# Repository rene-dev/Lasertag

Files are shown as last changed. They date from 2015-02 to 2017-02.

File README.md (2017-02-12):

# Lasertag
pew pew!
Ein freies und offenes Lasertag Projekt der warpzone in Münster.

## Aktueller Stand
Hard- und Software haben viele Kinderkrankheiten, spielbar ist es noch nicht. Es existieren 2 Waffel-Prototypen mit tiefgezogenen Gehäusen und ein Paar Hitpoints. Westen wollen noch gebaut werden.
* __Hitpoint__: voll funktionsfähig aber dirty gecoded
* __Lasermodul__: Im groben funktioniert alles. Einige Pins sind falsch beschriftet. IR funktioniert, sendet auch ganz leicht wenn es nicht senden soll. Sound ist viel zu leise.
* __Pi__: Da ist noch einiges zu tun. Grundlegende Kommunikation mit den Modulen ist möglich. Grundlegender Server Client per TCP.

## Grundstruktur
In jeder Waffel steckt ein Raspberry Pi, ein Lasermodul und ein Hitpoint. Das Lasermodul ist ein HAT für den Pi und dient als Schnittstelle zur Waffel-Hardware. Die High-Level Kommunikation (Spielmodus, Powerups, Map, ...) zwischen den Pis läuft per WLAN. Die Low-Level Kommunikation (Player-ID, Schaden) per gebündeltem IR-LED-UART auf TSOP-Empfänger.

### Raspberry Pi
In Python wird Netzwerk gemacht, per I2C die Module angesprochen und das SPI-Touch-Display angesteuert.

### Lasermodul
Kommt in jede Waffel:
* Atmega 328p
* IR-LED zum Daten senden
* roten Laser, damit man auch was sieht (Klasse 1 mit deutschem Zertifikat)
* starke RGBW ansteuern für Lichteffekte
* Trefferzone über einen Front-TSOP
* Taster auslesen
* LiPo auf 5V Step-Up Wandler
* An-Aus Taster
* Akkuüberwachung
* Audioverstärker

### Hitpoint
Kommt in jede Waffel und mehrere an die Weste (Schultern, Bauch, Rücken, ...):
* Attiny 2313A
* 4 10mm RGB-LEDs
* 4 TSOP-IR-Empfänger

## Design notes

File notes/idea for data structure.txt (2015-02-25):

Config:

Waffe
 ID: uint16_t
 Name: string
 Schussmodi[]
  ID: uint16_t
  Munitionsname: string
  Schaden_Schild: uint16_t, Schild/Treffer
  Schaden_Körper: uint16_t, leben/Treffer
  Leben_absaugen: uint16_t, leben/s
  heilen: uint16_t, leben/s
  Schussfrequenz: uint16_t, ms
  Magazingröße: uint32_t
  Anzahl_Schüsse: uint32_t
  Nachladezeit: uint16_t, ms
  Laser_Farbe: uint8_t
  Laser_Schusslänge: uint16_t, ms
  Sound_Schuss: string
  Sound_Schuss_magazin_leer: string
  Sound_nachladen: string
  Sound_getroffen_werden: string
  Haptik
  
Player
 ID: uint16_t
 Name: string
 Team: uint8_t
 Leben: uint16_t
 Leben_max: uint16_t
 Schild: uint16_td
 Schild_max: uint16_t
 aktuelle Waffe: uint16_t
 verfügbare Waffen[]

Spielmodus
 Name: string
 erlaubte Waffen[]
 Teams_janein: boolean
 Team_Anzahl: uint8_t
 Team_maxSpieler: uint8_t
 Scharfschalten mit Knopf vorne: boolean
 Flashlight an bei scharf: teamfarbe, weiss, aus
 TrefferzonenLED_Schultern: teamfarbe, weiss, aus
 TrefferzonenLED_vorne: teamfarbe, weiss, aus
 TrefferzonenLED_hinten: teamfarbe, weiss, aus
 TrefferzonenLED_Waffe: teamfarbe, weiss, aus

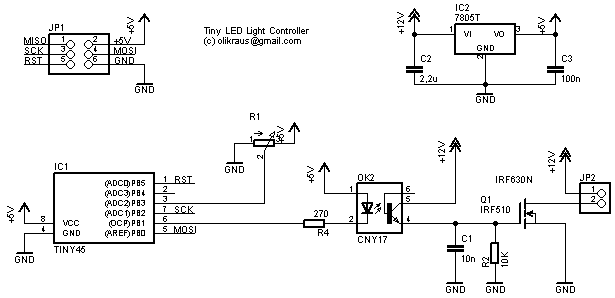
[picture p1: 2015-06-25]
notes/onoff.png

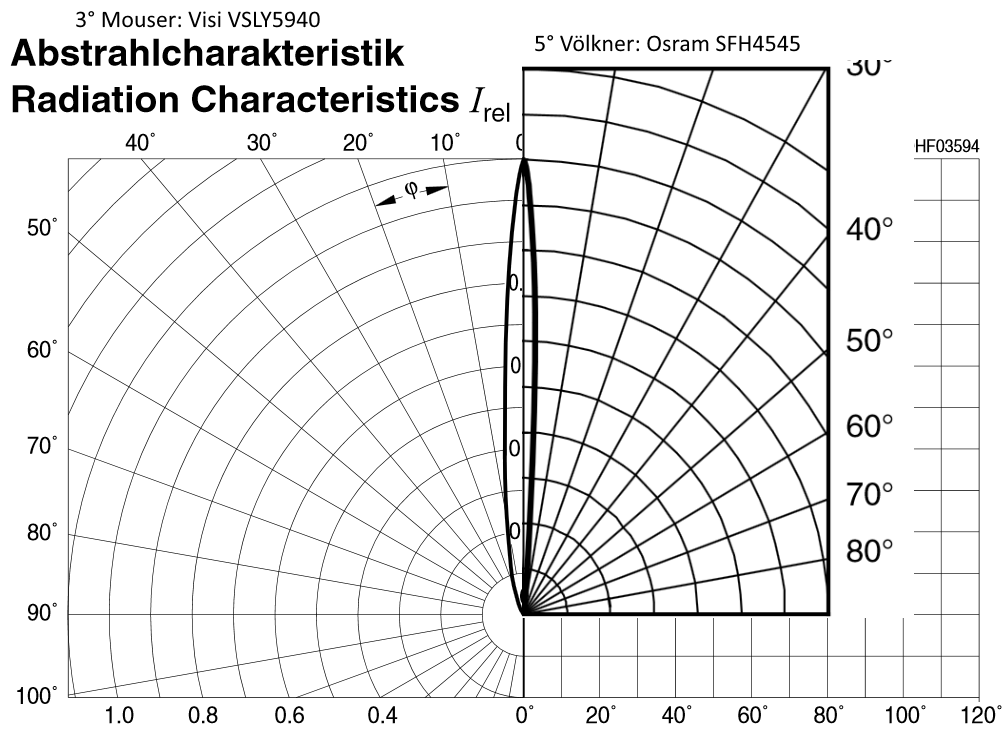
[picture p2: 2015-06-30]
notes/ir led comparison.png

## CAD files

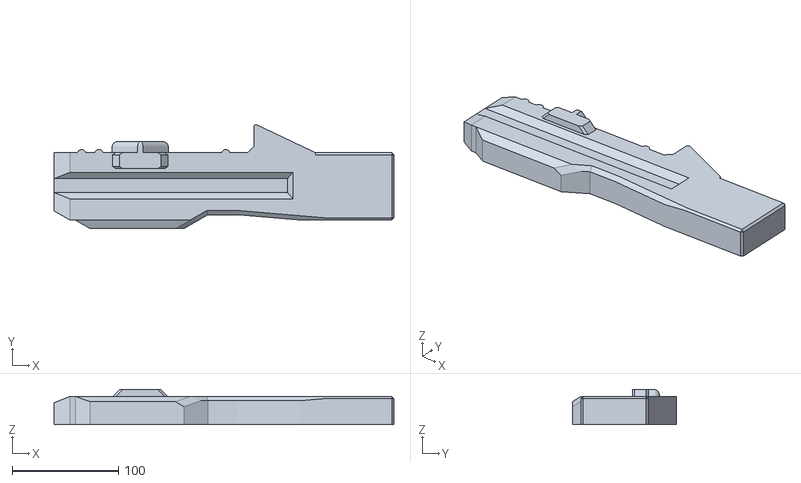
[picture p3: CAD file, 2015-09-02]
case/fräsen/case1a.stl
320.3 x 98.1 x 33.0

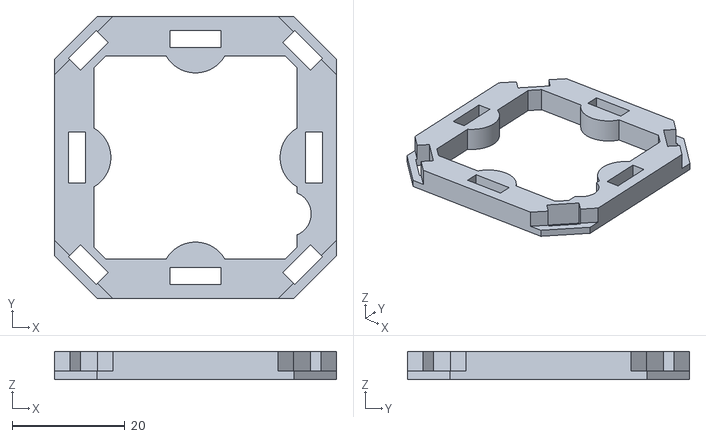
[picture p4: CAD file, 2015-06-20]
hitpoint/3dprinting/hitpoint_frame.stl
50.0 x 50.0 x 5.00

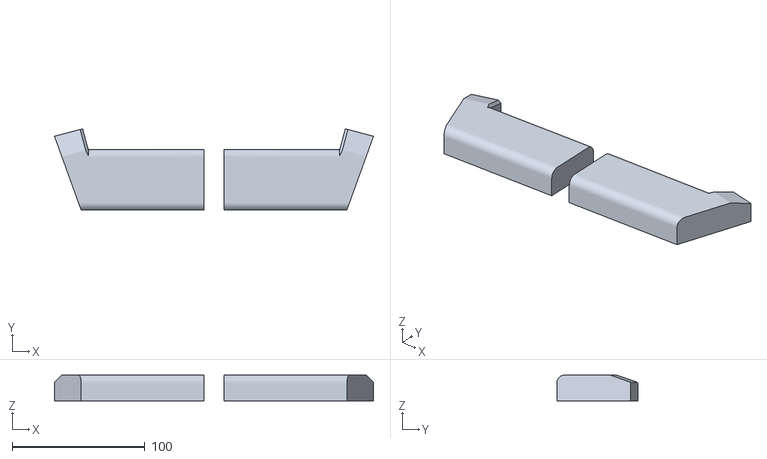
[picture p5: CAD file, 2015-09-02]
case/fräsen/case2.stl
240.7 x 61.5 x 19.5

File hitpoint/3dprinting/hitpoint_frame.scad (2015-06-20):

rotate(90, [1, 0, 0])
{
difference()
{
	// the whole platform
	intersection()
	{
		cube([50, 5, 50], center = true);
		rotate(45, [0, 1, 0])
			cube([60, 5, 60], center = true);
	}
	for(i=[0:3])
	{
		rotate(i*90, [0, 1, 0])
		{
			// ir recv pin holes
			translate([19, 0, 19])
				rotate(45, [0, 1, 0])
					cube([7, 5, 3], center = true);

			translate([23, 0.75, 23])
				intersection()
				{
					rotate(45, [0, 1, 0])
						cube([20, 3.5, 9], center = true);
				}

			// led pin holes
			translate([0, 0, 21])
				cube([9, 5, 3], center = true);
		}
	}

	difference()
	{
		// big hole in the center
		intersection()
		{
			cube([36, 5, 36], center = true);
			rotate(45, [0, 1, 0])
				cube([48, 5, 48], center = true);
		}
		// led platforms
		for(i=[0:3])
		{
			rotate(i*90, [0, 1, 0])
			{
				translate([0, 0, 21])
					rotate(90, [1, 0, 0])
						cylinder(r = 12/2, h = 5, center = true, $fn = 360);
			}
		}
	}

	// capacitor
	translate([16.5, 0, 10])
		rotate(90, [1, 0, 0])
			cylinder(r = 8/2, h = 6, center = true, $fn = 360);
}
}

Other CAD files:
case/fräsen/case1b.stl
case/IR sende dings.skp
case/Lautsprecher.skp
case/case.skp
case/zutaten/Raspberry-Pi-B+-slp.skp

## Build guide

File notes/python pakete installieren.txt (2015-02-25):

sudo apt-get install python-pip
sudo apt-get install python-twisted

pip updaten:
sudo pip install -U pip
sudo pip install --upgrade setuptools

sudo pip install twisted

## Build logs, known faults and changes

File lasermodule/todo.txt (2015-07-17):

ripup @;
layer cream und mask
min leiterbahnbreite 0,032 inch =0,8mm für 4a
pgnd, agnd? am amp? masseführung?
analog spule, 100n?
benennung
pi connector spiegelung
atmega vor den step up? nö
battery connector mehr als 1a
kann backlight pwm pi pin auch pwm?
4,7u nach ldo reichen??
lötjumper r kombipad zum durchschneiden am amp
spule
lötjumper an p-fet pi
extension port evtl jst-xh?
alle gnd pinne vom pi nehmen

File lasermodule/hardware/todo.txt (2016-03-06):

schrift weiter weg von kleinfutter
atmega schrift drehen
3,3, 5v? an ldoschreiben
opto diode markieren
onoff an 2 atmegapins !? pb0 ist gut
ok=ltv817
r25=3,3k
tasterfootprints für anaus
display connector beschriftung
elkos beide seiten + und beschriftung
lcd backlight an +!! und nicht an den uln
wirklich 2 laser nötig?
laser und so anschluss nach vorne?
wo ist haptik?
 am besten: laser_2 = laser_1, laser_1 = haptik (weil pwm)
ok richtung anzeichnen
fets an und rev nicht lesbar wenn verlötet
optionale an led: 2kohm an 5v

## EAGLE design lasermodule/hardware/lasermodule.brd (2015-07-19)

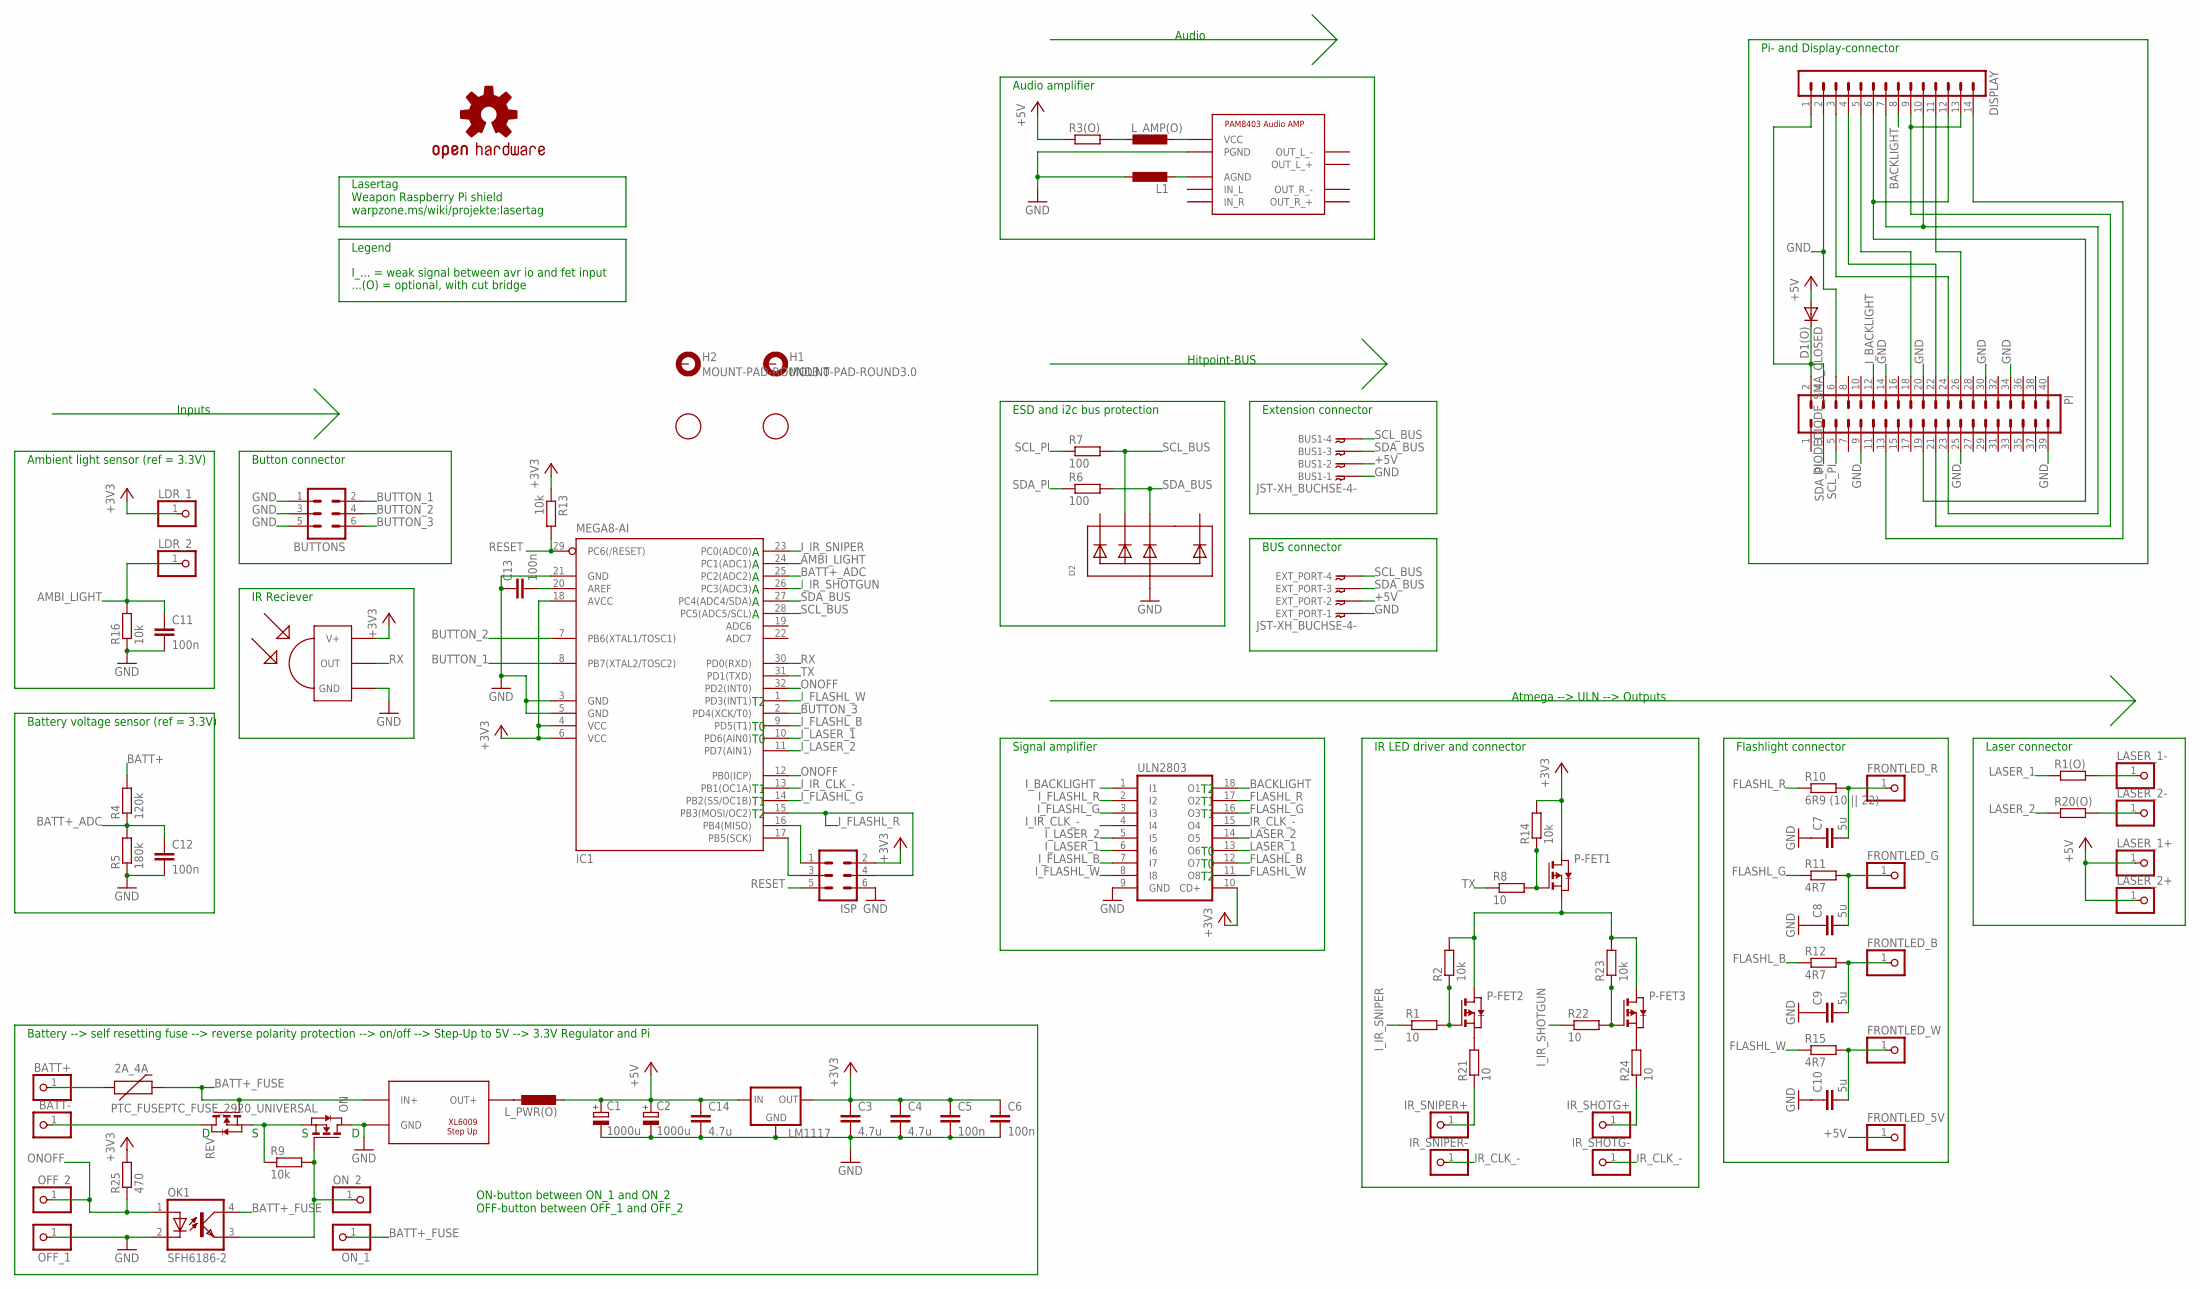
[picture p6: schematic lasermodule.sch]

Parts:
2A_4A: PTC_FUSEPTC_FUSE_2920_UNIVERSAL; PTC_FUSE_2920_UNIVERSAL
BATT+: PIN-HEADER-1PIN-HEADER-1_BIG; PIN-HEADER-1_BIG
BATT-: PIN-HEADER-1PIN-HEADER-1_BIG; PIN-HEADER-1_BIG
BUS1: JST-XH_BUCHSE-4-; JST-XH_BUCHSE-4
BUTTONS: PIN-HEADER-3X2
C1, C2: 1000u; C_UNIVERSAL_PAD
C3, C4, C14: 4.7u; 0805
C5, C6, C11, C12, C13: 100n; 0603
C7, C8, C9, C10: 5u; 0805
D1(O): DIODEDIODE_SMA_CLOSED; DIODE_SMA_CLOSED
D2: ESD-SCHUTZ; SOT363
DISPLAY: PIN-HEADER-DISPLAY
EXT_PORT: JST-XH_BUCHSE-4-; JST-XH_BUCHSE-4
FRONTLED_5V: PIN-HEADER-1PIN-HEADER-1; PIN-HEADER-1
FRONTLED_B: PIN-HEADER-1PIN-HEADER-1; PIN-HEADER-1
FRONTLED_G: PIN-HEADER-1PIN-HEADER-1; PIN-HEADER-1
FRONTLED_R: PIN-HEADER-1PIN-HEADER-1; PIN-HEADER-1
FRONTLED_W: PIN-HEADER-1PIN-HEADER-1; PIN-HEADER-1
H1, H2: MOUNT-PAD-ROUND3.0; 3,0-PAD
IC1: MEGA8-AI; TQFP32-08
IR_SHOTG+: PIN-HEADER-1PIN-HEADER-1; PIN-HEADER-1
IR_SHOTG-: PIN-HEADER-1PIN-HEADER-1; PIN-HEADER-1
IR_SNIPER+: PIN-HEADER-1PIN-HEADER-1; PIN-HEADER-1
IR_SNIPER-: PIN-HEADER-1PIN-HEADER-1; PIN-HEADER-1
ISP: PIN-HEADER-3X2
L1: L-EUL2825P; L2825P
LASER_1+, LASER_1-, LASER_2+, LASER_2-: PIN-HEADER-1PIN-HEADER-1; PIN-HEADER-1
LDR_1, LDR_2: PIN-HEADER-1PIN-HEADER-1; PIN-HEADER-1
LM1117: LM1117_3V3_REGULATOR; SOT223
LOGO1: OSHW-LOGOM; OSHW-LOGO-M
L_AMP(O): L; L_5MM_CLOSED
L_PWR(O): L; L_5MM_CLOSED
OFF_1, OFF_2: PIN-HEADER-1PIN-HEADER-1; PIN-HEADER-1
OK1: SFH6186-2; SMD4-7
ON: N-MOSFET; TO252
ON_1, ON_2: PIN-HEADER-1PIN-HEADER-1; PIN-HEADER-1
P-FET1, P-FET2, P-FET3: PMOSSOT23; SOT-23
PI: PIN-HEADER-20X2
R1, R8, R21, R22, R24: 10; 0603
R1(O), R20(O): R_EU0603_CLOSED; 0603_CLOSED
R2, R9, R13, R14, R16, R23: 10k; 0603
R3(O): R_EU0805_CLOSED; 0805_CLOSED
R4: 120k; 0603
R5: 180k; 0603
R6, R7: 100; 0603
R10: 6R9 (10 || 22); 0603
R11, R12, R15: 4R7; 0603
R25: 470; 0603
REV: N-MOSFET; TO252
U$1: TSOP1838; TSOP18XX
U$3: XL6009-STEPUP-BOARD
U$4: PAM8403-AMP-BOARD
U$5, U$6: FIDUCIAL; FIDUCIAL_1MM
ULN2803: ULN2803ASO18; SO18W

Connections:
+3V3: C3.1, C4.1, C5.1, C6.1, IC1.4 (VCC), IC1.6 (VCC), IC1.18 (AVCC), ISP.2, LDR_1.1, LM1117.2 (OUT), LM1117.4 (OUT), P-FET1.1 (D), R13.1, R14.2, R25.2, U$1.VCC (V+), ULN2803.10 (CD+)
+5V: BUS1.P$2, C1.+, C2.+, C14.1, D1(O).A, EXT_PORT.P$2, FRONTLED_5V.1, LASER_1+.1, LASER_2+.1, LM1117.3 (IN), L_PWR(O).2, R3(O).1
AMBI_LIGHT: C11.1, IC1.24 (PC1(ADC1)), LDR_2.1, R16.2
BACKLIGHT: DISPLAY.8, ULN2803.18 (O1)
BATT+: 2A_4A.P$1 (1), BATT+.1, R4.2
BATT+_ADC: C12.1, IC1.25 (PC2(ADC2)), R4.1, R5.2
BATT+_FUSE: 2A_4A.P$2 (2), OK1.4 (COL), ON_1.1, REV.1 (G), U$3.IN+
BATT-: BATT-.1, REV.3 (D)
BUTTON_1: BUTTONS.2, IC1.8 (PB7(XTAL2/TOSC2))
BUTTON_2: BUTTONS.4, IC1.7 (PB6(XTAL1/TOSC1))
BUTTON_3: BUTTONS.6, IC1.2 (PD4(XCK/T0))
EASTEREGG_NET: P-FET1.2 (S), P-FET2.1 (D), P-FET3.1 (D), R2.2, R23.2
FLASHL_B: R12.1, ULN2803.12 (O7)
FLASHL_G: R11.1, ULN2803.16 (O3)
FLASHL_R: R10.1, ULN2803.17 (O2)
FLASHL_W: R15.1, ULN2803.11 (O8)
GND: BUS1.P$1, BUTTONS.1, BUTTONS.3, BUTTONS.5, C1.-, C2.-, C3.2, C4.2, C5.2, C6.2, C7.1, C8.1, C9.1, C10.1, C11.2, C12.2, C13.1, C14.2, D2.2 (A), DISPLAY.2, EXT_PORT.P$1, IC1.3 (GND), IC1.5 (GND), IC1.21 (GND), ISP.6, L1.1, LM1117.1 (GND), OFF_1.1, OK1.2 (C), ON.3 (D), PI.6, PI.9, PI.14, PI.20, PI.25, PI.30, PI.34, PI.39, R5.1, R16.1, U$1.GND, U$3.GND_IN (GND), U$3.GND_OUT (GND), U$4.PGND, ULN2803.9 (GND)
IR_CLK_-: IR_SHOTG-.1, IR_SNIPER-.1, ULN2803.15 (O4)
IR_SHOTGUN_TX_+: IR_SHOTG+.1, R24.1
IR_SNIPER_TX_+: IR_SNIPER+.1, R21.1
I_BACKLIGHT: PI.12, ULN2803.1 (I1)
I_FLASHL_B: IC1.9 (PD5(T1)), ULN2803.7 (I7)
I_FLASHL_G: IC1.14 (PB2(SS/OC1B)), ULN2803.3 (I3)
I_FLASHL_R: IC1.15 (PB3(MOSI/OC2)), ISP.4, ULN2803.2 (I2)
I_FLASHL_W: IC1.1 (PD3(INT1)), ULN2803.8 (I8)
I_IR_CLK_-: IC1.13 (PB1(OC1A)), ULN2803.4 (I4)
I_IR_SHOTGUN: IC1.26 (PC3(ADC3)), R22.1
I_IR_SNIPER: IC1.23 (PC0(ADC0)), R1.1
I_LASER_1: IC1.10 (PD6(AIN0)), ULN2803.6 (I6)
I_LASER_2: IC1.11 (PD7(AIN1)), ULN2803.5 (I5)
LASER_1: R1(O).1, ULN2803.13 (O6)
LASER_1-: LASER_1-.1, R1(O).2
LASER_2: R20(O).1, ULN2803.14 (O5)
LASER_2-: LASER_2-.1, R20(O).2
LCD_CS: DISPLAY.3, PI.24
LCD_DC: DISPLAY.5, PI.18
LCD_MISO: DISPLAY.9, DISPLAY.13, PI.21
LCD_MOSI: DISPLAY.6, DISPLAY.12, PI.19
LCD_RESET: DISPLAY.4, PI.22
LCD_SCK: DISPLAY.7, DISPLAY.10, PI.23
LCD_TOUCH_CS: DISPLAY.11, PI.26
LCD_TOUCH_IRQ: DISPLAY.14, PI.13
unnamed: L1.2, U$4.AGND
unnamed: IC1.16 (PB4(MISO)), ISP.1
unnamed: IC1.17 (PB5(SCK)), ISP.3
unnamed: C7.2, FRONTLED_R.1, R10.2
unnamed: P-FET1.3 (G), R8.2, R14.1
unnamed: C13.2, IC1.20 (AREF)
unnamed: P-FET2.3 (G), R1.2, R2.1
unnamed: C8.2, FRONTLED_G.1, R11.2
unnamed: C9.2, FRONTLED_B.1, R12.2
unnamed: C10.2, FRONTLED_W.1, R15.2
unnamed: L_PWR(O).1, U$3.OUT+
unnamed: ON.2 (S), R9.1, REV.2 (S)
unnamed: P-FET2.2 (S), R21.2
unnamed: D1(O).C, DISPLAY.1, PI.2, PI.4
unnamed: L_AMP(O).2, R3(O).2
unnamed: L_AMP(O).1, U$4.VCC
unnamed: P-FET3.2 (S), R24.2
unnamed: P-FET3.3 (G), R22.2, R23.1
ONOFF: IC1.12 (PB0(ICP)), IC1.32 (PD2(INT0)), OFF_2.1, OK1.1 (A), R25.1
ONOFF_2: OK1.3 (EMIT), ON.1 (G), ON_2.1, R9.2
RESET: IC1.29 (PC6(/RESET)), ISP.5, R13.2
RX: IC1.30 (PD0(RXD)), U$1.OUT
SCL_BUS: BUS1.P$4, D2.3 (C2), EXT_PORT.P$4, IC1.28 (PC5(ADC5/SCL)), R7.2
SCL_PI: PI.5, R7.1
SDA_BUS: BUS1.P$3, D2.4 (C3), EXT_PORT.P$3, IC1.27 (PC4(ADC4/SDA)), R6.2
SDA_PI: PI.3, R6.1
TX: IC1.31 (PD1(TXD)), R8.1

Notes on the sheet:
Flashlight connector
Laser connector
BUS connector
ESD and i2c bus protection
IR Reciever
Audio amplifier
Battery --> self resetting fuse --> reverse polarity protection --> on/off --> Step-Up to 5V --> 3.3V Regulator and Pi
Pi- and Display-connector
Battery voltage sensor (ref = 3.3V)
Ambient light sensor (ref = 3.3V)
IR LED driver and connector
Signal amplifier
Button connector
Extension connector
I_... = weak signal between avr io and fet input
Legend
...(O) = optional, with cut bridge
Hitpoint-BUS
ON-button between ON_1 and ON_2 OFF-button between OFF_1 and OFF_2
Atmega --> ULN --> Outputs
Inputs
Audio
Lasertag Weapon Raspberry Pi shield warpzone.ms/wiki/projekte:lasertag

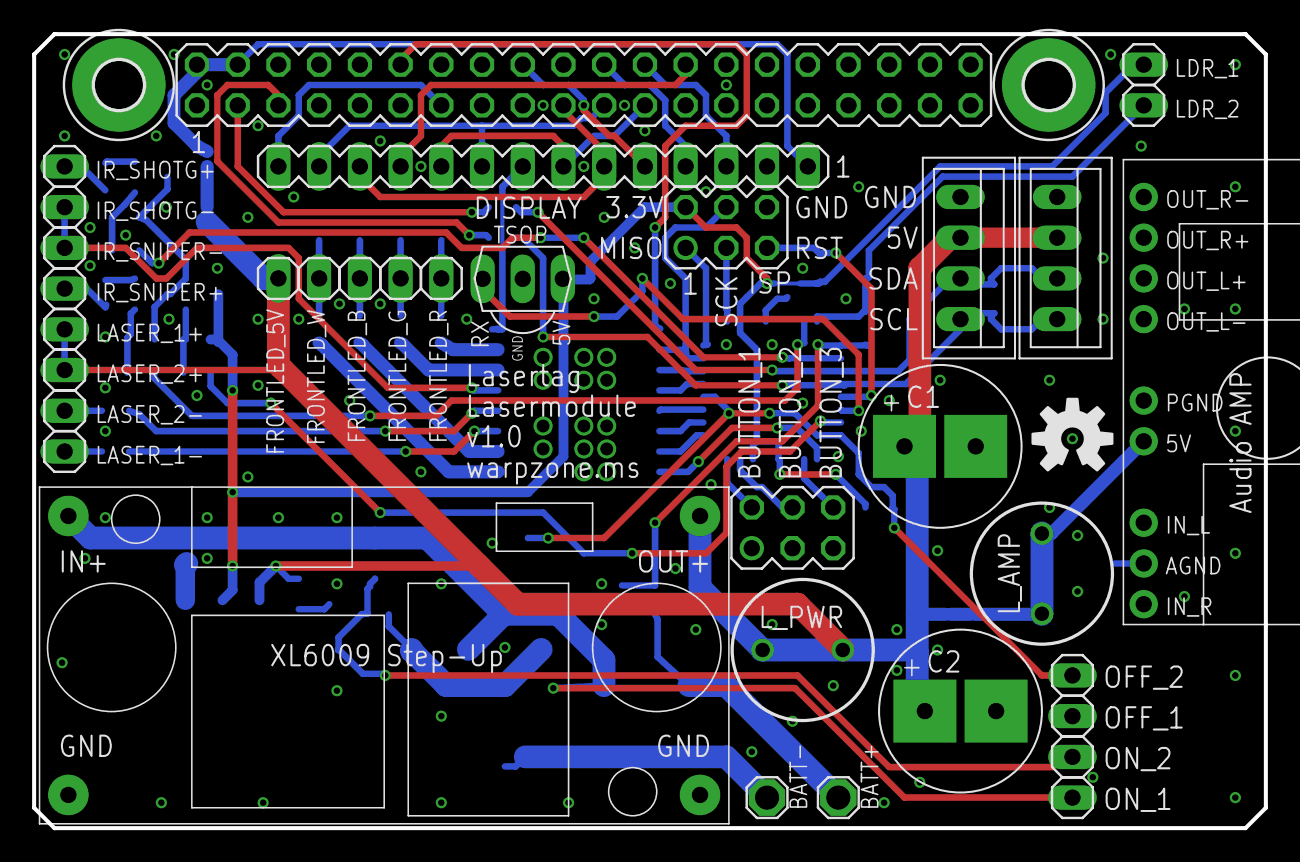
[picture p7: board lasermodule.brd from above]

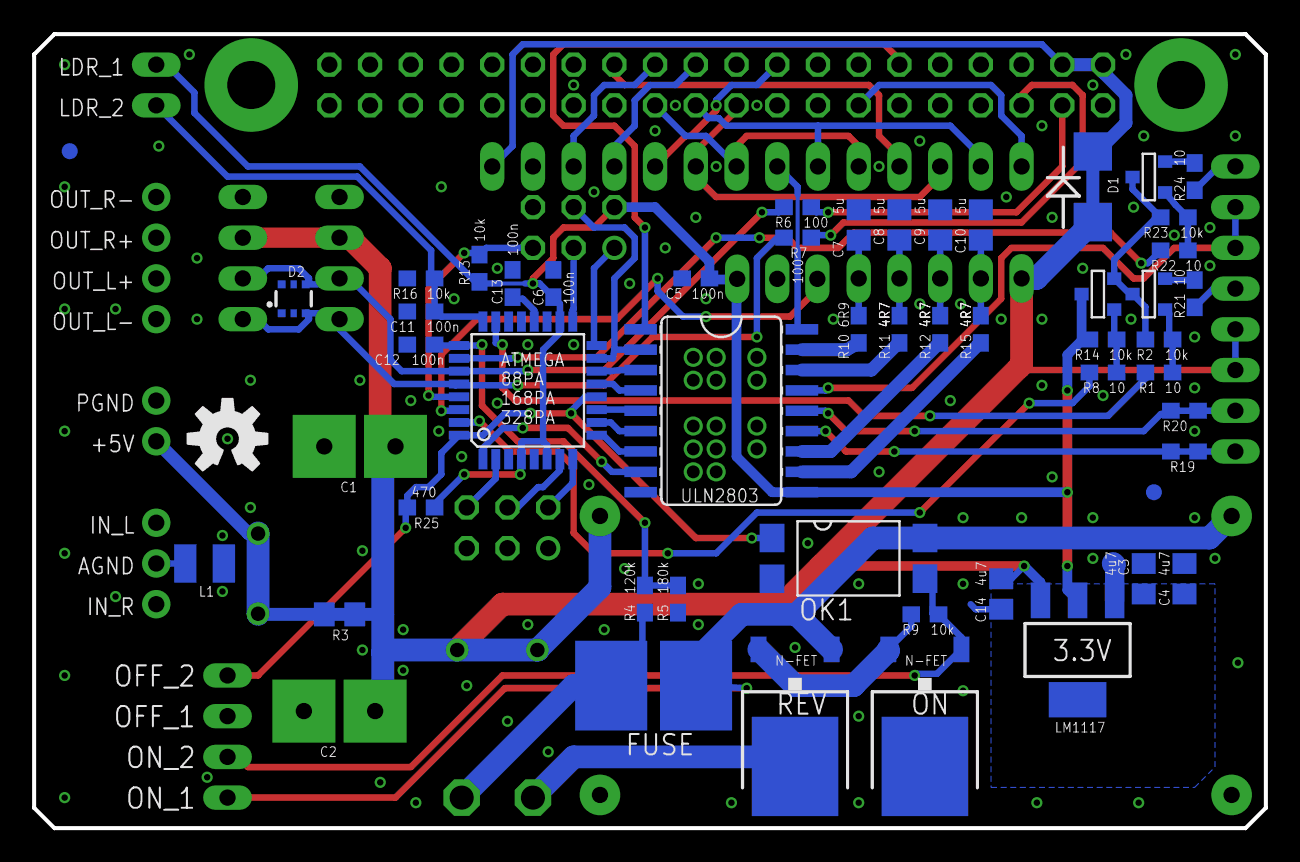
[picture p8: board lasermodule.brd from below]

Board: 2 copper layers, 76.8 x 49.5 mm, 89 parts (51 on the bottom side), 69 nets.

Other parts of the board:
LOGO2: OSHW-LOGOM; OSHW-LOGO-M
U$2: PI2

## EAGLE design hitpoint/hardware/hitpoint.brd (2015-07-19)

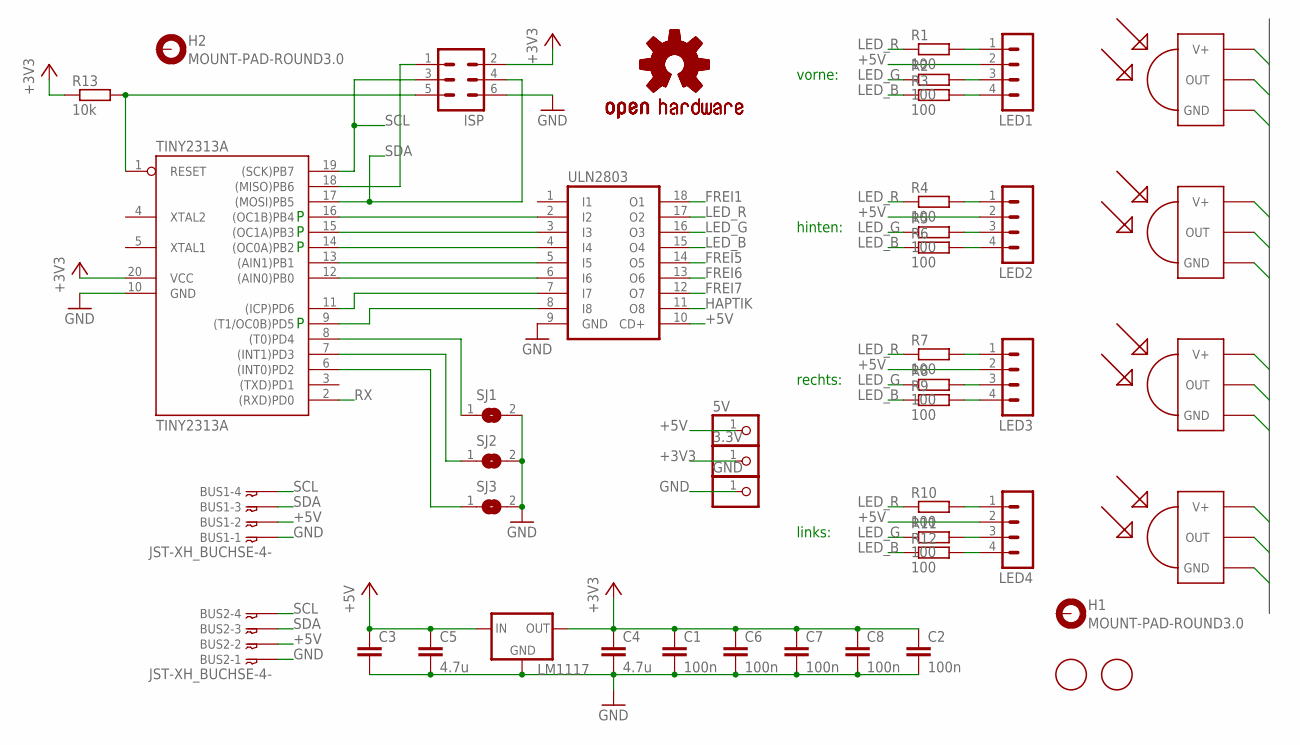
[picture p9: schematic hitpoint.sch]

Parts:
3.3V, 5V: PIN-HEADER-1
BUS1, BUS2: JST-XH_BUCHSE-4-; JST-XH_BUCHSE-4
C1, C2, C6, C7, C8: 100n; 0603
C3: C_EUCAP_UNIVERSAL; C_UNIVERSAL
C4, C5: 4.7u; 0805
GND: PIN-HEADER-1
H1, H2: MOUNT-PAD-ROUND3.0; 3,0-PAD
ISP: PIN-HEADER-3X2
LED1, LED2, LED3, LED4: PIN-HEADER-4
LM1117: LM1117_3V3_REGULATOR; SOT223
LOGO1, LOGO2: OSHW-LOGOM; OSHW-LOGO-M
R1, R2, R3, R4, R5, R6, R7, R8, R9, R10, R11, R12: 100; 0603
R13: 10k; 0603
SJ1, SJ2, SJ3: SJ
TINY2313A: TINY2313A; SO20LVERSTUMMELT
U$1, U$2, U$3, U$4: TSOP4338
U$5, U$6: FIDUCIAL; FIDUCIAL_1MM
ULN2803: ULN2803ASO18; SO18W

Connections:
+3V3: 3.3V.1, C1.1, C2.1, C4.1, C6.1, C7.1, C8.1, ISP.2, LM1117.2 (OUT), LM1117.4 (OUT), R13.1, TINY2313A.20 (VCC), U$1.VCC (V+), U$2.VCC (V+), U$3.VCC (V+), U$4.VCC (V+)
+5V: 5V.1, BUS1.P$2, BUS2.P$2, C3.1, C3.1B (1), C5.1, LED1.2, LED2.2, LED3.2, LED4.2, LM1117.3 (IN), ULN2803.10 (CD+)
FREI1: ULN2803.18 (O1)
FREI5: ULN2803.14 (O5)
FREI6: ULN2803.13 (O6)
FREI7: ULN2803.12 (O7)
GND: BUS1.P$1, BUS2.P$1, C1.2, C2.2, C3.2, C3.2B (2), C4.2, C5.2, C6.2, C7.2, C8.2, GND.1, ISP.6, LM1117.1 (GND), SJ1.2, SJ2.2, SJ3.2, TINY2313A.10 (GND), U$1.GND, U$2.GND, U$3.GND, U$4.GND, ULN2803.9 (GND)
HAPTIK: ULN2803.11 (O8)
LED_B: R3.1, R6.1, R9.1, R12.1, ULN2803.15 (O4)
LED_G: R2.1, R5.1, R8.1, R11.1, ULN2803.16 (O3)
LED_R: R1.1, R4.1, R7.1, R10.1, ULN2803.17 (O2)
unnamed: ISP.1, TINY2313A.18 ((MISO)PB6)
unnamed: SJ1.1, TINY2313A.8 ((T0)PD4)
unnamed: TINY2313A.16 ((OC1B)PB4), ULN2803.2 (I2)
unnamed: TINY2313A.15 ((OC1A)PB3), ULN2803.3 (I3)
unnamed: LED4.1, R10.2
unnamed: LED4.3, R11.2
unnamed: TINY2313A.14 ((OC0A)PB2), ULN2803.4 (I4)
unnamed: TINY2313A.13 ((AIN1)PB1), ULN2803.5 (I5)
unnamed: TINY2313A.12 ((AIN0)PB0), ULN2803.6 (I6)
unnamed: TINY2313A.11 ((ICP)PD6), ULN2803.7 (I7)
unnamed: TINY2313A.9 ((T1/OC0B)PD5), ULN2803.8 (I8)
unnamed: LED4.4, R12.2
unnamed: LED3.1, R7.2
unnamed: LED3.3, R8.2
unnamed: LED3.4, R9.2
unnamed: LED2.1, R4.2
unnamed: LED2.3, R5.2
unnamed: SJ2.1, TINY2313A.7 ((INT1)PD3)
unnamed: SJ3.1, TINY2313A.6 ((INT0)PD2)
unnamed: LED2.4, R6.2
unnamed: ISP.5, R13.2, TINY2313A.1 (RESET)
unnamed: LED1.1, R1.2
unnamed: LED1.3, R2.2
unnamed: LED1.4, R3.2
RX: TINY2313A.2 ((RXD)PD0), U$1.OUT, U$2.OUT, U$3.OUT, U$4.OUT
SCL: BUS1.P$4, BUS2.P$4, ISP.3, TINY2313A.19 ((SCK)PB7)
SDA: BUS1.P$3, BUS2.P$3, ISP.4, TINY2313A.17 ((MOSI)PB5)

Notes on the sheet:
vorne:
hinten:
rechts:
links:

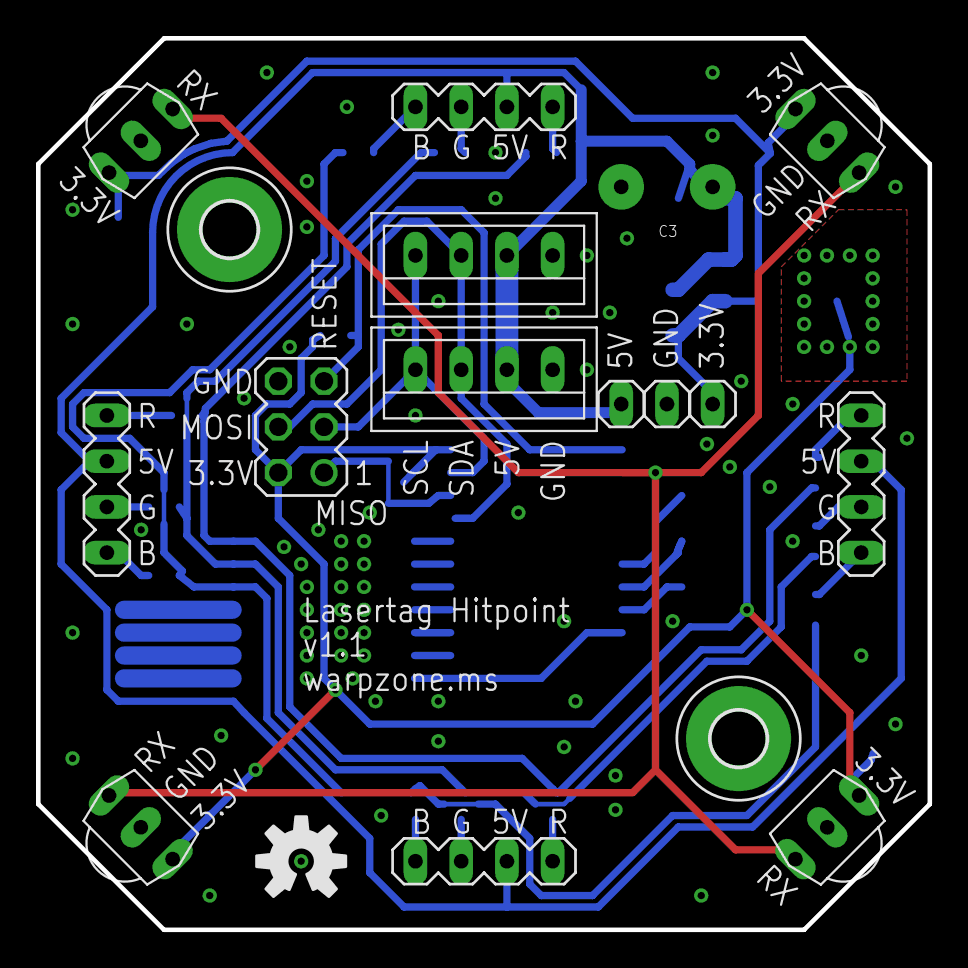
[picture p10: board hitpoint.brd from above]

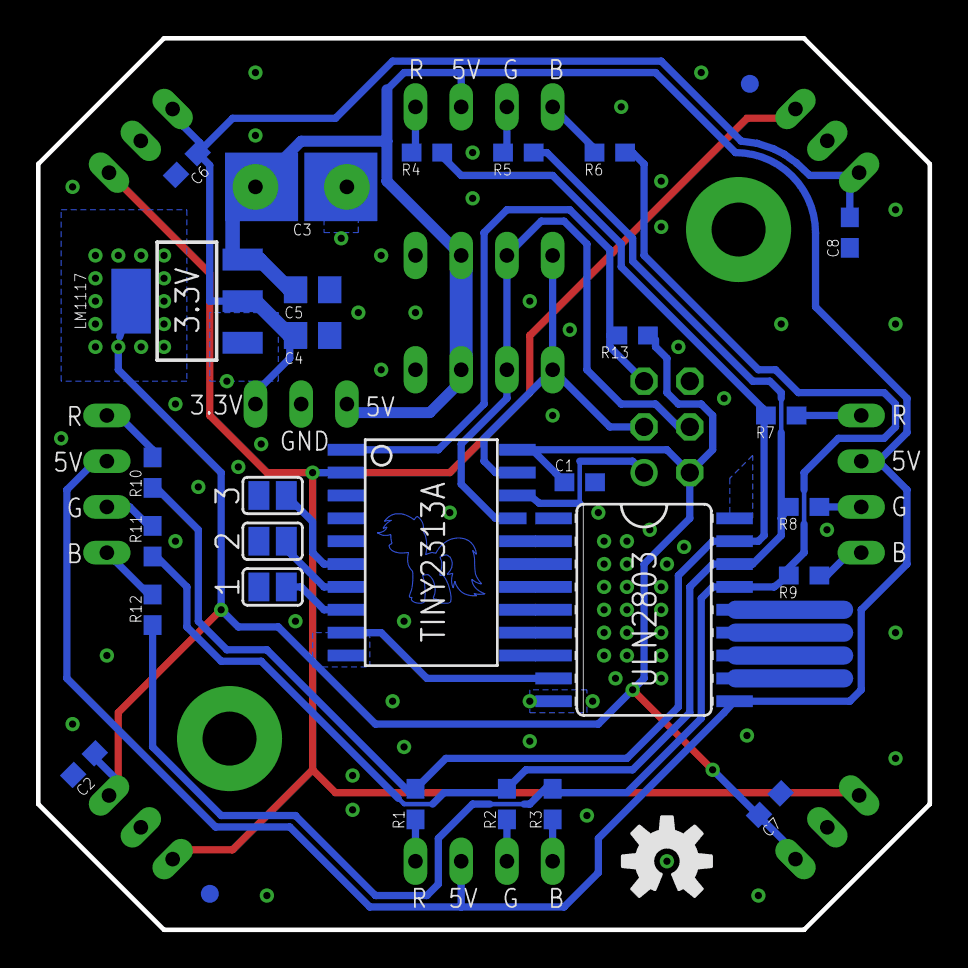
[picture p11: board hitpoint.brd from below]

Board: 2 copper layers, 49.5 x 49.5 mm, 47 parts (30 on the bottom side), 33 nets.

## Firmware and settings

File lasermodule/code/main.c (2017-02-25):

//Lasermodule

#define F_CPU 8000000

#include <avr/io.h>
#include <avr/interrupt.h>
#include <stdint.h>
#include <string.h>
#include <util/delay.h>
#include "twislave.h"

//---------------------------- Pins and PWM Registers ----------------------------

#define LASER PD7 //laser 2
#define HAPTIK OCR0A //laser 1
#define LED_FRONT_B OCR0B
#define IR_CLOCK_DUTY_CYCLE OCR1A
#define LED_FRONT_G OCR1B
#define LED_FRONT_R OCR2A
#define LED_FRONT_W OCR2B
#define BUTTON_1 PB7
#define BUTTON_2 PB6
#define BUTTON_3 PD4
#define ONOFF PB0

//---------------------------- i2c Settings ----------------------------

#define I2C_BUS_ADRESS 0x03 //Weapon Lasermodule

#define LED_FRONT_REG 0
typedef struct{
	uint8_t r;
	uint8_t g;
	uint8_t b;
	uint8_t w;
} led_front_t;
static volatile led_front_t led_front_buffer;

#define LASER_REG 4
typedef struct{
	uint8_t laser; //laser 2
} laser_t;
static volatile laser_t laser_buffer;

#define HAPTIK_REG 7
typedef struct{
	uint8_t vibrate; //laser 1
} haptik_t;
static volatile haptik_t haptik_buffer;

#define BUTTON_REG 10
typedef struct{
	uint8_t button_1;
	uint8_t button_2;
	uint8_t button_3;
} button_t;
static volatile button_t button_buffer;

#define SHOOT_REG 20
typedef struct{
	uint8_t enable; //20, Fire once if written > 0
	uint8_t playerid; //21
	uint8_t damage; //22
	uint8_t laser; //23
	uint8_t laser_duration; //24, Laser light duration
	uint8_t vibrate_power; //25
	uint8_t vibrate_duration; //26
	uint8_t muzzle_flash_r; //27
	uint8_t muzzle_flash_g; //28
	uint8_t muzzle_flash_b; //29
	uint8_t muzzle_flash_w; //30
	uint8_t muzzle_flash_duration; //31
} shoot_t;
static volatile shoot_t shoot_buffer;

#define HIT_REG 40
typedef struct{
	uint8_t enable; //Hit if enabled
	uint8_t playerid;
	uint8_t damage;
} hit_t;
static volatile hit_t hit_buffer;

#define MISC_REG 50
typedef struct{
	uint8_t v_bat_l;
	uint8_t v_bat_r;
	uint8_t ldr_l;
	uint8_t ldr_r;
} misc_t;
static volatile misc_t misc_buffer;

//logarithmic pwm fading: http://www.mikrocontroller.net/articles/LED-Fading
//const uint8_t pwmtable64[64] PROGMEM = 
const uint8_t pwmtable64[64] = 
{
    1, 1, 2, 2, 2, 2, 3, 3, 3, 3, 4, 4, 5, 5, 6, 6, 7, 7, 8, 8, 9, 10, 11, 12, 13, 14, 15, 16, 18, 19, 21, 22, 24, 26, 28, 30, 33, 35, 38, 41, 45, 48, 52, 56, 61, 65, 71, 76, 82, 89, 96, 103, 111, 120, 129, 140, 151, 162, 175, 189, 203, 219, 237, 255
};

//---------------------------- UART init ----------------------------

//UART http://www.mikrocontroller.net/articles/AVR-GCC-Tutorial/Der_UART
#define BAUD 1200UL      // Baudrate

// Berechnungen
#define UBRR_VAL ((F_CPU+BAUD*8)/(BAUD*16)-1)   // clever runden
#define BAUD_REAL (F_CPU/(16*(UBRR_VAL+1)))     // Reale Baudrate
#define BAUD_ERROR ((BAUD_REAL*1000)/BAUD) // Fehler in Promille, 1000 = kein Fehler.

#if ((BAUD_ERROR<990) || (BAUD_ERROR>1010))
  #error Systematischer Fehler der Baudrate grösser 1% und damit zu hoch! 
#endif

//----------------------------  ----------------------------

uint8_t crc8(const void *vptr, int len){
	const uint8_t *data = vptr;
	unsigned crc = 0;
	int i, j;
	for (j = len; j; j--, data++) {
		crc ^= (*data << 8);
		for(i = 8; i; i--) {
			if (crc & 0x8000)
			crc ^= (0x1070 << 3);
			crc <<= 1;
		}
	}
	return (uint8_t)(crc >> 8);
}

uint32_t map32(uint32_t x, uint32_t in_min, uint32_t in_max, uint32_t out_min, uint32_t out_max)
{
  return (x - in_min) * (out_max - out_min + 1) / (in_max - in_min + 1) + out_min;
}

uint16_t map16(uint16_t x, uint16_t in_min, uint16_t in_max, uint16_t out_min, uint16_t out_max)
{
  return (x - in_min) * (out_max - out_min + 1) / (in_max - in_min + 1) + out_min;
}

uint8_t map8(uint8_t x, uint8_t in_min, uint8_t in_max, uint8_t out_min, uint8_t out_max)
{
  return (x - in_min) * (out_max - out_min + 1) / (in_max - in_min + 1) + out_min;
}

uint8_t taster(volatile uint8_t *port, uint8_t pin)
{
	if(!(*port & (1 << pin))){
		//LED_FRONT_R=240;
		return 1;
	}else{
		//LED_FRONT_R=255;
		return 0;
	}
}

ISR(USART_RX_vect){
	//hit: PlayerID Schaden crc8_checksum
	static uint8_t rx[3];
	rx[0] = rx[1]; //nach links durchschieben
	rx[1] = rx[2];
	rx[2] = UDR0;

	if(crc8(rx, 2) == rx[2]){
		hit_buffer.playerid = rx[0];
		hit_buffer.damage = rx[1];
		hit_buffer.enable = 1;
	}
}

void USART_Transmit( unsigned char data )
{
	/* Wait for empty transmit buffer */
	while ( !( UCSR0A & (1<<UDRE0)) ){}
	/* Put data into buffer, sends the data */
	UDR0 = data;
}

ISR(TIMER0_OVF_vect){
	// if(counter++ == 38){
		// millis++;
		// counter=0;
	// }
}

uint8_t laser(uint8_t on){
	static uint8_t laser_status;
	if(on == 1){
		PORTD |= (1 << LASER);
		laser_status = on;
	}else if(on == 0){
		PORTD &= ~(1 << LASER);
		laser_status = on;
	}
	return laser_status;
}
	
volatile uint8_t i2c_last_reg_access = -1;

void i2c_slave_poll_buffer(unsigned char reg_addr, volatile unsigned char** buffer, volatile unsigned char* buffer_length){
	// switch(reg_addr){
		// case LED_FRONT_REG ... LED_FRONT_REG + sizeof(led_front_t) - 1:
			// *buffer        = &((uint8_t *)&led_front_buffer)[reg_addr-LED_FRONT_REG];
			// *buffer_length = (sizeof(led_front_t)-reg_addr);
			// i2c_last_reg_access = LED_FRONT_REG;
			// break;
		// case LASER_REG ... LASER_REG + sizeof(laser_front_t) - 1:
			// *buffer        = &((uint8_t *)&laser_front_buffer)[reg_addr-LASER_REG];
			// *buffer_length = (sizeof(laser_front_t)-reg_addr);
			// i2c_last_reg_access = LASER_REG;
			// break;

	if ((reg_addr >= LED_FRONT_REG) && (reg_addr < (LED_FRONT_REG + sizeof(led_front_t)))){
		*buffer        = &((uint8_t *)&led_front_buffer)[reg_addr-LED_FRONT_REG];
		*buffer_length = sizeof(led_front_t)-(reg_addr-LED_FRONT_REG);
		i2c_last_reg_access = LED_FRONT_REG;
	} else if ((reg_addr >= BUTTON_REG) && (reg_addr < (BUTTON_REG + sizeof(button_t)))){ //10-12
		*buffer        = &((uint8_t *)&button_buffer)[reg_addr-BUTTON_REG];
		*buffer_length = sizeof(button_t)-(reg_addr-BUTTON_REG);
		i2c_last_reg_access = BUTTON_REG;
	} else if ((reg_addr >= LASER_REG) && (reg_addr < (LASER_REG + sizeof(laser_t)))){
		*buffer        = &((uint8_t *)&laser_buffer)[reg_addr-LASER_REG];
		*buffer_length = sizeof(laser_t)-(reg_addr-LASER_REG);
		i2c_last_reg_access = LASER_REG;
	} else if ((reg_addr >= HAPTIK_REG) && (reg_addr < (HAPTIK_REG + sizeof(haptik_t)))){
		*buffer        = &((uint8_t *)&haptik_buffer)[reg_addr-HAPTIK_REG];
		*buffer_length = sizeof(haptik_t)-(reg_addr-HAPTIK_REG);
		i2c_last_reg_access = HAPTIK_REG;
	} else if ((reg_addr >= SHOOT_REG) && (reg_addr < (SHOOT_REG + sizeof(shoot_t)))){
		*buffer        = &((uint8_t *)&shoot_buffer)[reg_addr-SHOOT_REG];
		*buffer_length = sizeof(shoot_t)-(reg_addr-SHOOT_REG);
		i2c_last_reg_access = SHOOT_REG;
	} else if ((reg_addr >= HIT_REG) && (reg_addr < (HIT_REG + sizeof(hit_t)))){
		*buffer        = &((uint8_t *)&hit_buffer)[reg_addr-HIT_REG];
		*buffer_length = sizeof(hit_t)-(reg_addr-HIT_REG);
		i2c_last_reg_access = HIT_REG;
	} else if ((reg_addr >= MISC_REG) && (reg_addr < (MISC_REG + sizeof(misc_t)))){
		*buffer        = &((uint8_t *)&misc_buffer)[reg_addr-MISC_REG];
		*buffer_length = sizeof(misc_t)-(reg_addr-MISC_REG);
		i2c_last_reg_access = MISC_REG;
	} else {
		*buffer_length = 0;
		*buffer = 0;
	}
}

void i2c_slave_write_complete(void){
}

void i2c_slave_read_complete(void){
	if (i2c_last_reg_access == HIT_REG) hit_buffer.enable = 0;
}

int main(void){
	// 12 PB0 LASER_R  ---- NICHT MEHR ----
	// 11 PD7 LASER								(Laser)
	// 10 PD6 HAPTIK		OC0A	Timer0	 8 Bit	(Haptik)
	//  9 PD5 LED_FRONT_B	OC0B	Timer0	 8 Bit
	// 13 PB1 IR_CLOCK_-	OC1A	Timer1	16 Bit
	// 14 PB2 LED_FRONT_G	OC1B	Timer1	16 Bit
	// 15 PB3 LED_FRONT_R	OC2A	Timer2	 8 Bit
	//  1 PD3 LED_FRONT_W	OC2B	Timer2	 8 Bit
	// 24 PC1 LDR			ADC1
	// 25 PC2 V_BATT		ADC2
	//  2 PD4 BUTTON_3
	//  7 PB6 BUTTON_2
	//  8 PB7 BUTTON_1
	// 12 PB0 ONOFF

	cli();

	//set pins
	DDRB |= (1 << DDB1) | (1 << DDB2) | (1 << DDB3); //OUTPUT
	DDRD |= (1 << DDD3) | (1 << DDD5) | (1 << DDD6) | (1 << DDD7); //OUTPUT
	DDRB &= ~(1 << PB6) & ~(1 << PB7); //INPUT
	PORTB |= (1 << PB6) | (1 << PB7); //input pullup
	DDRD &= ~(1 << PD4); //INPUT
	PORTD |= (1 << PD4); //input pullup
	
	//ausschalten
	//DDRB |= (1 << DDB0); //OUTPUT
	//PORTB &= ~(1 << DDB0); //LOW

	//init Timers for PWM:
	//https://sites.google.com/site/qeewiki/books/avr-guide/pwm-on-the-atmega328
	//WGM* s157: fast pwm without ctc
	//CS*  s158: _BV(CS20) = prescaler 1 (gilt für a und b)
	//PWM_fequency = clock_speed / [Prescaller_value * (1 + TOP_Value) ] = 8000000/(1*(1+210)) = 37.915 kHz
	
	//Timer 0: Mode 3: Fast PWM, TOP: 0xFF, Update of OCRx: Bottom, TOV1 Flag set on: TOP, Prescaler: 1, Set OC0x on Compare Match
	TCCR0A = _BV(COM0B0) | _BV(COM0A0) | _BV(COM0B1) | _BV(COM0A1) | _BV(WGM00) | _BV(WGM01);
	TCCR0B = _BV(CS00);
	//TIMSK0 |= (1<<TOIE0); //Overflow Interrupt for count millis
	
	//Timer 2: Mode 3: Fast PWM, TOP: 0xFF, Update of OCRx: Bottom, TOV1 Flag set on: TOP, Prescaler: 1, Set OC2x on Compare Match
	TCCR2A = _BV(COM2B0) | _BV(COM2A0) | _BV(COM2B1) | _BV(COM2A1) | _BV(WGM20) | _BV(WGM21);
	TCCR2B = _BV(CS20);
	
	//Timer 1: Mode 14: Fast PWM, inverting mode, Top: ICR1, Update of OCR1x: Bottom, TOV1 Flag set on: TOP, Prescaler: 1
	//https://docs.google.com/spreadsheets/d/1HadMDsU0MGo1LXUr1gKNFrfe4wX_Bq9kbVIwOvD3chk
	TCCR1A = _BV(COM1B0) | _BV(COM1A0) | _BV(COM1B1) | _BV(COM1A1) | _BV(WGM11);
	TCCR1B = _BV(CS10) | _BV(WGM12) | _BV(WGM13);

	//IR carrier frequency to 37.915 kHz:
	ICR1 = 210;
	//IR carrier frequency duty cycle to 50%:
	IR_CLOCK_DUTY_CYCLE = ICR1-ICR1/2;
	
	//switch off all light
	LED_FRONT_R=255;
	LED_FRONT_G=ICR1;
	LED_FRONT_B=255;
	LED_FRONT_W=255;
	HAPTIK=255; //haptik
	//PORTB |= (1 << PB0); //an
	
	//i2c init
	init_twi_slave(I2C_BUS_ADRESS<<1);

	//UART init
	UBRR0H = UBRR_VAL >> 8;
	UBRR0L = UBRR_VAL & 0xFF;
	UCSR0B |= _BV(TXEN0) | _BV(RXEN0) | _BV(RXCIE0); //UART RX, TX und RX-Interrupt einschalten
	UCSR0C = (1<<UCSZ01) | (1<<UCSZ00); //Asynchron 8N1 
	
	sei(); // enable Interrupts global
	
	uint32_t laser_duration_counter=0;
	uint32_t vibrate_duration_counter=0;
	uint32_t muzzle_flash_duration_counter=0;
	uint32_t muzzle_flash_duration_counter_max=0; //fürs ausfaden
	uint16_t ir_delay=0;
	uint8_t ir_count=255;
	
			// return links*256 + rechts
	uint16_t battt = 12345;
	misc_buffer.v_bat_l = battt>>8;
	misc_buffer.v_bat_r = battt;
	
 	while(1){
		// ---------------- shoot ----------------
		if (shoot_buffer.enable){
			laser_buffer.laser = shoot_buffer.laser;
			laser_duration_counter = (uint32_t)shoot_buffer.laser_duration*200;
			haptik_buffer.vibrate = shoot_buffer.vibrate_power;
			vibrate_duration_counter = (uint32_t)shoot_buffer.vibrate_duration*200;
			led_front_buffer.r = shoot_buffer.muzzle_flash_r;
			led_front_buffer.g = shoot_buffer.muzzle_flash_g;
			led_front_buffer.b = shoot_buffer.muzzle_flash_b;
			led_front_buffer.w = shoot_buffer.muzzle_flash_w;
			muzzle_flash_duration_counter = (uint32_t)shoot_buffer.muzzle_flash_duration*200;
			muzzle_flash_duration_counter_max = muzzle_flash_duration_counter; //fürs ausfaden
			shoot_buffer.enable = 0;
			ir_count = 0;
		}
		
		if(ir_delay < 1500){ //delay zwischen ir paketen
			ir_delay++;
		}else{
			if(ir_count < 3){ //x ir pakete
				uint8_t array[] = {shoot_buffer.playerid, shoot_buffer.damage};
				USART_Transmit(shoot_buffer.playerid); //IR_TX: PlayerID
				USART_Transmit(shoot_buffer.damage); //IR_TX: Schaden
				USART_Transmit(crc8(array, 2)); //IR_TX: crc8 checksum
				ir_count++;
			}
			ir_delay = 0;
		}
		
		if(laser_duration_counter >= 2){ //laser an zeit
			laser_duration_counter--;
		}
		if(laser_duration_counter == 1){
			laser_buffer.laser = 0;
			// haptik_buffer.vibrate = 0;
			laser_duration_counter = 0; //damit man den laser auch ohne shoot anmachen kann
		}
		
		if(vibrate_duration_counter >= 2){ //vibrate an zeit
			vibrate_duration_counter--;
		}
		if(vibrate_duration_counter == 1){
			haptik_buffer.vibrate = 0;
			vibrate_duration_counter = 0; //damit man es auch ohne shoot anmachen kann
		}
		
		if(muzzle_flash_duration_counter >= 2){ //muzzle_flash an zeit
			// led_front_buffer.r = pwmtable_8D[map(muzzle_flash_duration_counter, (uint32_t)shoot_buffer.muzzle_flash_duration*200, 1, 31, 0)];
			led_front_buffer.r = pwmtable64[map32(muzzle_flash_duration_counter, muzzle_flash_duration_counter_max, 1, map32(shoot_buffer.muzzle_flash_r, 0, 255, 0, 63), 0)]; //ausfaden
			// led_front_buffer.r = pwmtable64[map(muzzle_flash_duration_counter, muzzle_flash_duration_counter_max, 1, 63, 0)]; //ausfaden
			muzzle_flash_duration_counter--;
		}
		if(muzzle_flash_duration_counter == 1){
			led_front_buffer.r = 0;
			led_front_buffer.g = 0;
			led_front_buffer.b = 0;
			led_front_buffer.w = 0;
			muzzle_flash_duration_counter = 0; //damit man es auch ohne shoot anmachen kann
		}
		
		// ---------------- output ----------------
		LED_FRONT_R = 255-led_front_buffer.r;
		LED_FRONT_G = ICR1-map8(led_front_buffer.g, 0, 255, 0, ICR1);
		LED_FRONT_B = 255-led_front_buffer.b;
		LED_FRONT_W = 255-led_front_buffer.w;
		laser(laser_buffer.laser);
		HAPTIK = 255-haptik_buffer.vibrate;
		
		// ---------------- input ----------------
		button_buffer.button_1 = taster(&PINB, BUTTON_1);
		button_buffer.button_2 = taster(&PINB, BUTTON_2);
		button_buffer.button_3 = taster(&PIND, BUTTON_3);

		// ---------------- input ----------------
	}
}

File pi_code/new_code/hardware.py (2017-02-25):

#!/usr/bin/python

import smbus


class I2CAddresses(object):
    BROADCAST = 0x00
    WEAPON = 0x03
    HITPOINT_WEAPON = 0x04
    HITPOINT0 = 0x04
    HITPOINT1 = 0x05
    HITPOINT2 = 0x06
    HITPOINT3 = 0x07
    HITPOINT4 = 0x08


class WeaponRegisters(object):
    LED_R = 0  # OUTPUT, Front-RGBW-LED: [0, 255]
    LED_G = 1  # OUTPUT, Front-RGBW-LED: [0, 255]
    LED_B = 2  # OUTPUT, Front-RGBW-LED: [0, 255]
    LED_W = 3  # OUTPUT, Front-RGBW-LED: [0, 255]
    LASER = 4  # OUTPUT, Laser (Platinenbeschriftung "Laser 2"): [0, 1]
    VIBRATION = 7  # OUTPUT, Vibrationsmotor (Platinenbeschriftung "Laser 1"): [0, 255] VORSICHT!
    BUTTON0 = 10  # INPUT,  Button
    BUTTON1 = 11  # INPUT,  Schwarz
    BUTTON2 = 12  # INPUT,  Rot
    SHOOT_ENABLED = 20  # OUTPUT, Fur Schuss auf 1 setzen, setzt sich selbst zuruck: [0, 1]
    SHOOT_PLAYERID = 21  # OUTPUT, Wird bei Schuss per IR gesendet: [0, 255]
    SHOOT_DAMAGE = 22  # OUTPUT, Wird bei Schuss per IR gesendet: [0, 255]
    SHOOT_LASER = 23  # OUTPUT, Laser an bei Schuss: [0, 1]
    SHOOT_LASER_DURATION = 24  # OUTPUT, Laser wie lange an bei Schuss: [0, 255] Einheit??
    SHOOT_VIBRATE_POWER = 25  # OUTPUT, Vibrationsmotor wie stark an bei Schuss, 0 == garnicht: [0, 255] VORSICHT!
    SHOOT_VIBRATE_DURATION = 26  # OUTPUT, Vibrationsmotor wie lange an bei Schuss: [0, 255] Einheit??
    SHOOT_MUZZLE_FLASH_R = 27  # OUTPUT, Front-RGBW-LED Helligkeit bei Schuss: [0, 255]
    SHOOT_MUZZLE_FLASH_G = 28  # OUTPUT, Front-RGBW-LED Helligkeit bei Schuss: [0, 255]
    SHOOT_MUZZLE_FLASH_B = 29  # OUTPUT, Front-RGBW-LED Helligkeit bei Schuss: [0, 255]
    SHOOT_MUZZLE_FLASH_W = 30  # OUTPUT, Front-RGBW-LED Helligkeit bei Schuss: [0, 255]
    SHOOT_MUZZLE_FLASH_DURATION = 31  # OUTPUT, Front-RGBW-LED wie lange an bei Schuss: [0, 255] Einheit??
    HIT_ENABLE = 40  # INPUT,  1 wenn getroffen, setzt sich bei Auslesen auf 0 zuruck: [0, 1]
    HIT_PLAYERID = 41  # INPUT,  PlayerID des Schutzen: [0, 255]
    HIT_DMG = 42  # INPUT,  Angerichteter Schaden: [0, 255]
    V_BAT_L = 50  # INPUT,  Akkustand 16-Bit Wert zusammen mit V_BAT_R: [0, 255]
    V_BAT_R = 51  # INPUT,  Akkustand 16-Bit Wert zusammen mit V_BAT_L: [0, 255]
    LDR_L = 52  # INPUT,  Helligkeit 16-Bit Wert zusammen mit LDR_R: [0, 255]
    LDR_R = 53  # INPUT,  Helligkeit 16-Bit Wert zusammen mit LDR_L: [0, 255]


class HitpointRegisters(object):
    VIBRATION = 7  # OUTPUT, Vibrationsmotor: [0, 255] Noch nicht in Hardware vorhanden.
    HIT_ENABLE = 30  # INPUT,  1 wenn getroffen, setzt sich bei Auslesen auf 0 zuruck: [0, 1]
    HIT_PLAYERID = 31  # INPUT,  PlayerID des Schutzen: [0, 255]
    HIT_DMG = 32  # INPUT,  Angerichteter Schaden: [0, 255]
    LED_R = 50  # OUTPUT, 4 RGB-LEDs: [0, 255]
    LED_G = 51  # OUTPUT, 4 RGB-LEDs: [0, 255]
    LED_B = 52  # OUTPUT, 4 RGB-LEDs: [0, 255]


class Hardware(object):
    def __init__(self):
        self.bus = None

        self.connect()

        self.set_weapon_lasers(laser=0)
        self.set_weapon_led(0, 0, 0, 0)
        self.set_hitpoint_led(I2CAddresses.HITPOINT_WEAPON, 0, 0, 0)


    # ----------------- low level -----------------
    def connect(self):
        try:
            self.bus = smbus.SMBus(0)  # alte PIs
        except:
            self.bus = smbus.SMBus(1)  # neuere PIs

    def disconnect(self):
        del self.bus

    def reconnect(self):
        self.disconnect()
        self.connect()

    def read(self, i2c_adr, register):
        while True:
            try:
                return self.bus.read_byte_data(i2c_adr, register)
            except IOError:
                self.reconnect()

    def write(self, i2c_adr, register, data):
        while True:
            try:
                self.bus.write_byte_data(i2c_adr, register, data)
                break
            except TypeError:
                print "Exception 'TypeError' in def write:", i2c_adr, register, data  # Debug informations
            except IOError:
                self.reconnect()

    # ----------------- Lasermodul -----------------

    def is_weapon_button_down(self, button):
        return self.read(I2CAddresses.WEAPON, WeaponRegisters.BUTTON0 + button) == 1

    def get_weapon_hit_results(self):
        player_id = self.read(I2CAddresses.WEAPON, WeaponRegisters.HIT_PLAYERID)
        damage = self.read(I2CAddresses.WEAPON, WeaponRegisters.HIT_DMG)
        enable = self.read(I2CAddresses.WEAPON, WeaponRegisters.HIT_ENABLE) != 0
        return enable, player_id, damage

    def get_weapon_vbat(self):
        left = self.read(I2CAddresses.WEAPON, WeaponRegisters.V_BAT_L)
        right = self.read(I2CAddresses.WEAPON, WeaponRegisters.V_BAT_R)
        return left * 256 + right   # TODO: Stimmt das so??

    def get_weapon_brightness(self):
        left = self.read(I2CAddresses.WEAPON, WeaponRegisters.LDR_L)
        right = self.read(I2CAddresses.WEAPON, WeaponRegisters.LDR_R)
        return left * 256 + right   # TODO: Stimmt das so??

    def set_weapon_characteristics(self, player_id, damage, laser, laser_duration, vibrate_power, vibrate_duration,
                                   muzzle_flash_r, muzzle_flash_g, muzzle_flash_b, muzzle_flash_w, muzzle_flash_duration):

        print "Weapon characteristics:"
        print "\tplayer_id:", player_id
        print "\tdamage:", damage
        print "\tlaser:", laser
        print "\tlaser_duration:", laser_duration
        print "\tvibrate_power:", vibrate_duration
        print "\tvibrate_duration:", vibrate_duration
        print "\tmuzzle_flash (r, g, b, w):", muzzle_flash_r, muzzle_flash_g, muzzle_flash_b, muzzle_flash_w
        print "\tmuzzle_flash_duration:", muzzle_flash_duration

        self.write(I2CAddresses.WEAPON, WeaponRegisters.SHOOT_PLAYERID, player_id)
        self.write(I2CAddresses.WEAPON, WeaponRegisters.SHOOT_DAMAGE, damage)
        self.write(I2CAddresses.WEAPON, WeaponRegisters.SHOOT_LASER, laser)
        self.write(I2CAddresses.WEAPON, WeaponRegisters.SHOOT_LASER_DURATION, laser_duration)
        self.write(I2CAddresses.WEAPON, WeaponRegisters.SHOOT_VIBRATE_POWER, vibrate_power)
        self.write(I2CAddresses.WEAPON, WeaponRegisters.SHOOT_VIBRATE_DURATION, vibrate_duration)
        self.write(I2CAddresses.WEAPON, WeaponRegisters.SHOOT_MUZZLE_FLASH_R, muzzle_flash_r)
        self.write(I2CAddresses.WEAPON, WeaponRegisters.SHOOT_MUZZLE_FLASH_G, muzzle_flash_g)
        self.write(I2CAddresses.WEAPON, WeaponRegisters.SHOOT_MUZZLE_FLASH_B, muzzle_flash_b)
        self.write(I2CAddresses.WEAPON, WeaponRegisters.SHOOT_MUZZLE_FLASH_W, muzzle_flash_w)
        self.write(I2CAddresses.WEAPON, WeaponRegisters.SHOOT_MUZZLE_FLASH_DURATION, muzzle_flash_duration)

    def shoot_weapon(self):
        self.write(I2CAddresses.WEAPON, WeaponRegisters.SHOOT_ENABLED, 1)
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

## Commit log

2014-11-16 interrupt und leuchten und so
2014-11-16 eagle files
    [Trefferzonenmodul.brd, Trefferzonenmodul.sch]
2014-11-19 Split PWM code to seperate file.
2014-11-19 Makefile: unify load and fuse targets into program target that does fuses and flash programming.
2014-11-19 Add initial I2C slave code. No real use yet.
2014-11-22 Enable LED color set via i2c
2014-12-04 hardware pwm
2014-12-04 makefile gefixt, und usbasp
2014-12-04 neue platine
    [Trefferzonenmodul.brd, Trefferzonenmodul.sch]
2014-12-05 i2c master
2014-12-05 Add i2c register 0x10 for last hit id.
2014-12-06 I2C: Fix i2c_slave_read_complete() not called after read due to copy-paste-error.
    [i2c_slave_usi.c]
2014-12-28 lasermodule added
2014-12-30 der overflow vom timer0 ist es
2015-01-03 UART: Don't enbale rx interrupt if the handler is not defined. UART: Configure USART before enabling it, not the other way round.
2015-01-16 reorganize folders, add hardware
    [DRILEGEND.CFG, Lasermodul.brd, Lasermodul.sch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]
2015-01-16 server comments
    [Lasermodul.brd, Lasermodul.sch]
2015-01-31 lasermodule: interrupt based i2c twi code
    compiled ohne fehler, dürfte aber nicht lauffähig sein
2015-02-22 alles neu gemacht
    [Lasermodul.brd, Lasermodul.sch]
2015-02-22 fix, notes added
    [Lasermodul.brd, Lasermodul.sch]
2015-02-25 server client
    [Config file.txt]
2015-03-03 hitpoint hardware, touch
    hitpoint: sda ist nun nicht mehr mit dem uln verbunden, pegel nun 3,3v
    statt 2,5v
    touch in x lauffähig
    oszi messungen am i2s hinzugefügt
    [Trefferzonenmodul.brd, Trefferzonenmodul.sch]
2015-04-12 Hitpoint v1.0, hitpoint 2 layer, lm i2c fix
    [DRILEGEND.CFG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]
2015-04-12 the real Hitpoint v1.0
    polygonbug and gerber export fixed
    [Trefferzonenmodul.brd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]
2015-05-06 the real real Hitpoint 1.0
    so wurden die ersten 20 platinen bestellt
    [Lasermodul.brd, Lasermodul.sch, lasermodul.sch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]
2015-06-11 clean-up, fixed sound latency
    [hardware.py, pew.py]
2015-06-11 removed addresses and registers from i2c.txt and added a note
2015-06-11 updated all scripts to use new hardware interface. worked around IOError issues on i2c bus by reconnecting and retrying...
    [hardware.py, hit_test.py, pew.py]
2015-06-18 laserbodul hardware weiter gemacht
    umstellung auf pi modul mit fast allem drauf
    [Lasermodul.brd, Lasermodul.sch]
2015-06-20 added 3d-printed hitpoint frame
    [frame.scad, frame.stl]
2015-06-20 increased led support size
    [frame.scad, frame.stl]
2015-06-20 weiter gemacht
    [Lasermodul.brd, Lasermodul.sch]
2015-06-21 lasermodul schaltplan rc1
    [IR sende dings.skp, Lasermodul.brd, Lasermodul.sch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]
2015-06-21 started plexi tiefzieh case
    [Lasermodul.brd, Lasermodul.sch, case.skp]
2015-06-21 deleted old crap
    [Lasermodul.brd, Lasermodul.sch, lasermodul.sch]
2015-06-22 lasermodul: second ir led added (shotgun, sniper)
    [Lasermodul.brd, Lasermodul.sch]
2015-06-22 Revert "lasermodul: second ir led added (shotgun, sniper)"
    This reverts commit 9edbfcc3dcd4b30951dc51917cfd3b2c003d7d33.
    [Lasermodul.brd, Lasermodul.sch]
2015-06-22 Revert "Revert "lasermodul: second ir led added (shotgun, sniper)""
    This reverts commit 1c5da857b2f96e4f5ecb9ad8f13985c8adc9d510.
    [Lasermodul.brd, Lasermodul.sch]
2015-06-22 nun ohne die .png!
2015-06-22 kleinere fixes lasermodul schaltplan
    [Lasermodul.brd, Lasermodul.sch]
2015-06-23 lasermodul: reverse polarity protection
    [Lasermodul.brd, Lasermodul.sch]
2015-06-25 another onoff
    [Lasermodul.brd, Lasermodul.sch]
2015-06-28 lasermodul routing started
    [Lasermodul.brd, Lasermodul.sch, connecting everything.ods]
2015-06-30 lots of bugs fixed
    [Lasermodul.brd, Lasermodul.sch, hitpoint_frame.scad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]
2015-07-01 was wieder raus genommen
    [Lasermodul.brd]
2015-07-04 lasermodul routing
    [Lasermodul.brd, Lasermodul.sch]
2015-07-12 routing and a bit case design
    [Lasermodul.brd, Lasermodul.sch, case.skp]
2015-09-02 case, code und so
    [case.skp, case1.stl, case1a.stl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]
2016-03-26 makefiles gefixed testprog ohne i2c für lasermodul
2017-02-11 Ole hat Semikolons aus python raus gemacht und Fehler behoben
    [hardware.py, lasertag.py, networkclient.py]
2017-02-18 Added other text to speech services and tools
    Added
    - googles current speech api
    (- espeak)
    - picospeaker
2017-02-18 pi einrichten neu gemacht, display mit overlay tuts nun
    [Pwm_table-r101.ods]
2017-02-19 created pycharm project fixed umlauts
    [hardware.py]
2017-02-22 class Hardware erbt nun von object
    Seit python2.2 wird es vorgesehen, dass Klassen immer von einen Typen erben
2017-02-23 Server fertig gemacht und Test fertig gemacht
2017-02-23 Fixed last commit (Files wurden nicht gemoved obwohl "git mv")
    [display.py, hardware.py, hardware_sim.py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]
2017-02-24 Bugs in Server gefixt + Client geschrieben
    [network_client.py, network_server.py]
2017-02-25 Fixed problem in hardware.py
    [hardware.py]
2017-02-25 Test für Hitpoint leds
2017-02-25 lasermodul: haptik fixed
2017-02-25 Vibration in hardware.py implementiert + changes an display.py
    [display.py, hardware.py]

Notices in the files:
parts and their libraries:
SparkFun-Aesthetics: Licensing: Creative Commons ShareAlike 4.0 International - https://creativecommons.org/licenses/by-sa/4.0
